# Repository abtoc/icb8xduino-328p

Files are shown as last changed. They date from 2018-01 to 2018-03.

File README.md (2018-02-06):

ICB8xduino-328p(kicadプロジェクト一式)
====

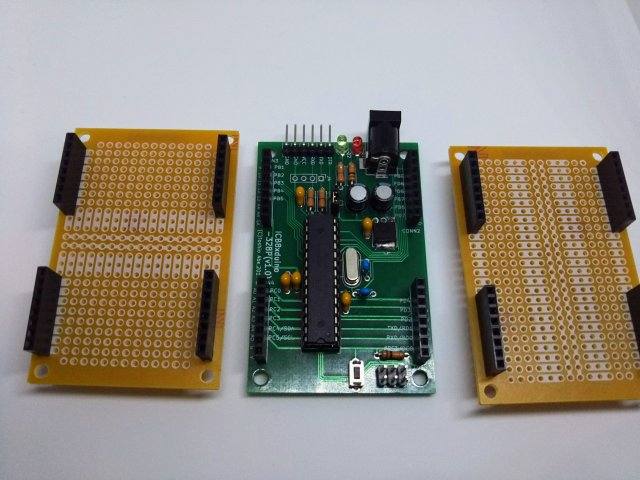
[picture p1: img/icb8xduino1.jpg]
写真1
  
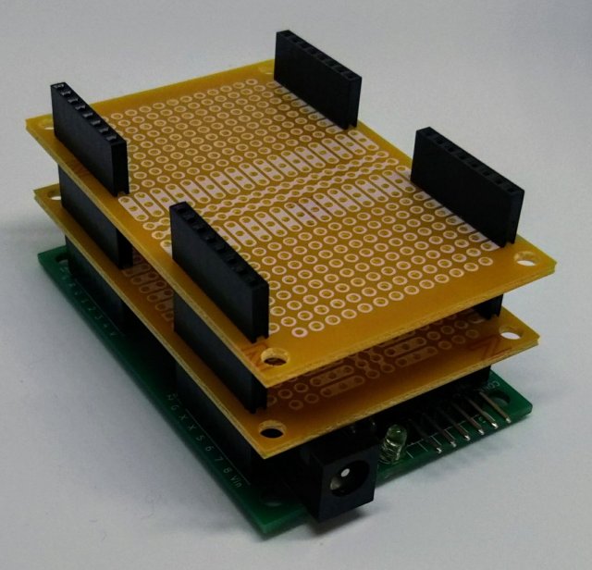
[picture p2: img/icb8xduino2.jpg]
写真2
  

ボードサイズをサンハヤト社製のICB-86,ICB-87のサイズに合わせたArduino互換基板です。
Arduino上でハードウェアのプロトタイプ作成者向けのボードになります。

目的とするシールドが無い場合は、ハードウェアの実装が必要になります。
が、下記のような問題に直面すると思います。

- 専用のユニバーサル基板を使用しなければならない
- 専用のユニバーサル基板の種類が限られる
- 100milピッチではないコネクタのため、アートワークが困難

本基板は、上記を考慮し、Arduinoプラットフォーム上で、
ハードウェア・プロトタイプ開発の手助けができれば幸いです。

## 特徴
- サイズはICB-86,ICB-87相当としています
- 基板の角のそれぞれにATmega328pのピンを全てアサインしています  
  また、ICB-86,ICB-87のコネクタパターンに合うよう配置しています

## 仕様
- ATmega328pで動作します
- クロックは16MHzクリスタル・レゾネータ及びインターナルクロック(8MHz)で動作可能です
- デジタルとアナログの電源はジャンパで分離しています
- 電源はUSBシリアル変換アダプター、ACアダプタ(コネクタ上のVINも含む)です  

## 使用方法
### 内容について
- kicadのプロジェクトファイル一式が入れられております
- ガーバーデータは garberディレクトリ に格納しております

|No. |ファイル名 |種類 |
|---:|:---|:---|
|1 |ICB8xduino-328p-F.Cu.gtl |トップレイヤ |
|2 |ICB8xduino-328p-B.Cu.gbl |ボトムレイヤ |
|3 |ICB8xduino-328p-F.Mask.gts |表面ソルダレジスト |
|4 |ICB8xduino-328p-B.Mask.gbs |裏面ソルダレジスト |
|5 |ICB8xduino-328p-F.SilkS.gto  |表面シルク |
|6 |ICB8xduino-328p-B.SilkS.gbo  |裏面シルク |
|7 |ICB8xduino-328p-Edge.Cuts.gm1|基板外形 |
|8 |ICB8xduino-328p.drl |スルーホール有ドリルデータ|
|9 |ICB8xduino-328p-NPTH.drl |スルーホール無ドリルデータ|

### [回路図](ICB8xduino-328p.pdf)

### パターン
- 前面  
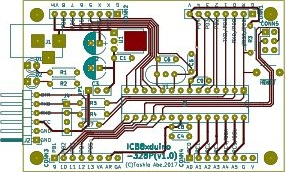
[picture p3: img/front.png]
  

- 背面  
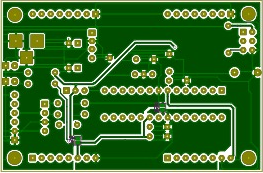
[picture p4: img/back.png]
  

### 部品表
|No. |Reference	 |部品名 |備考|
|---:|:---|:---|:---|
|1 |C1	 |積層セラミックコンデンサ 0.1μF | |
|2 |C2 	 |電解コンデンサ 47μF | |
|3 |C3 |電解コンデンサ 47μF | |
|4 |C4 |積層セラミックコンデンサ 0.1μF | |
|5 |C5  	 |積層セラミックコンデンサ 22pF |インターナルクロック、レゾネータ使用時は不要|
|6 |C6	 |積層セラミックコンデンサ 22pF |インターナルクロック、レゾネータ使用時は不要|
|7 |C7	 |積層セラミックコンデンサ 0.1μF | |
|8 |C8 |積層セラミックコンデンサ 0.1μF | |
|9 |C9 	 |積層セラミックコンデンサ 0.1μF | |
|10  |CONN1 |1x8 2.54mmピッチ ピンフレーム | |
|11  |CONN2	 |1x8 2.54mmピッチ ピンフレーム | |
|12  |CONN3	 |1x8 2.54mmピッチ ピンフレーム | |
|13  |CONN4	 |1x8 2.54mmピッチ ピンフレーム | |
|14  |CONN5	 |2x3 2.54mmピッチ ピンヘッダ | |
|15  |D1	 |3mm LED(赤) | |
|16  |D2	 |3mm LED(緑) | |
|17  |J1	 |2.1mm標準DCジャック | |
|18  |J2 	 |1x6 2.54mmピッチ ピンヘッダ(L型) | |
|19  |(J4) |秋月電子 AE-FT234X 用端子 |AT-FT234Xを使いたい場合に実装してください|
|20  |JP1	 |2x3 2.54mmピッチ ピンヘッダ | |
|21  |(JP1) |2.54ピッチ・ジャンパーピン | |
|22  |R1 	 |炭素皮膜抵抗器 10KΩ 1/4W (茶黒橙) | |
|23  |R2  	 |炭素皮膜抵抗器 330Ω 1/4W (橙橙茶) | |
|24  |R3	 |炭素皮膜抵抗器 10KΩ 1/4W (茶黒橙) | |
|25  |R4	 |炭素皮膜抵抗器 330Ω 1/4W (橙橙茶) | |
|26  |R5	 |炭素皮膜抵抗器 330Ω 1/4W (橙橙茶) | |
|27  |SW1	 |タクトスイッチ | |
|28  |U1	 |三端子レギュレータ 5V0.5A | |
|29  |U2	 |ATMEGA328P-PU | |
|30  |(U2) |ICソケット(28ピン,300mil) | |
|31  |Y1 |水晶振動子(16MHz)又はセラミック発振子(16MHz)|インターナルクロックの場合は不要|

### 実装
- GS1,GS2はハンダで接続してください。
- 内蔵クロックを使用する場合は、C5,C6及びクリスタルの実装は必要ありません。
- レゾネータを使用する場合は、C5,C6の実装は必要ありません。
- 電源をDCアダプタ(VIN端子含む)・USBシリアル変換アダプターのどちらかを、  
  ジャンパーで選択してください(回路図中JP1)
- Arduinoとして使用する場合は、AVRISP mk2でブートローダを書き込んでください  
  ブートローダ書き込み済のマイコンを使用する場合は不要です。また、
  ISCP端子も不要です
- ACアダプタの電源は三端子レギュレータの仕様に従ってください  
  本回路では12〜35Vを想定してます、

### ブートローダー書込
Arduinoとして使用する場合は、ブートローダーを書き込んでください  
※AVRISP mk2で書き込む場合

#### クリスタル、レゾネーターで使用する場合
```
avrdude \
-P usb            \
-b 19200          \
-c avrisp2        \
-p m328p          \
-v -e             \
-U efuse:w:0xFD:m \
-U hfuse:w:0xD6:m \
-U lfuse:w:0xFF:m

avrdude           \
-P usb            \
-b 19200          \
-c avrisp2        \
-p m328p          \
-v -e             \
-U lock:w:0xCF:m  \
-U flash:w:optiboot/optiboot_atmega328.hex

```

####  インターナル・クロックで使用する場合
```
avrdude \
-P usb            \
-b 19200          \
-c avrisp2        \
-p m328p          \
-v -e             \
-U efuse:w:0xFD:m \
-U hfuse:w:0xDA:m \
-U lfuse:w:0xE2:m

avrdude           \
-P usb            \
-b 19200          \
-c avrisp2        \
-p m328p          \
-v -e             \
-U lock:w:0xCF:m  \
-U flash:w:ATmegaBOOT_168_atmega328_pro_8MHz.hex
```
### スケッチ書き込み(Arduino IDE)
- スケッチの書き込みはUSBシリアル変換アダプターを使用してください  
  ピンアサインはArduino Proと同等にしてあります
- ボードの選択は下記の通りです
  - クリスタル、レゾネータの場合
    - ボード：Arduino/Genuino UNO
  - インターナルクロックの場合
    - ボード；Arduino Pro or Pro mini
    - プロセッサ：ATmega328P(3.3V, 8MHz)
- シリアルポートはUSBシリアル変換アダプターのポートを使用してください

## コネクタ
### CONN1
|No  |Aduino |ATmega328p |Pin |備考 |
|---:|---|---|---:|-----|
|1 |GNDD |GND |8 | |
|2 |RESET  |#RESET |1 | |
|3 |0 |PD0/RXD |2 | |
|4 |1 |PD1/TXD |3 | |
|5 |2 |PD2 |4 | |
|6 |3 |PD3 |5 | |
|7 |4 |PD4 |6 | |
|8 |VDD |VCC |7 | |

### CONN2
|No  |Aduino |ATmega328p |Pin |備考 |
|---:|---|---|---:|---|
|1 |GNDD |GND |8 | |
|2 |XTAL1  |PB6 |9 |内蔵クロックのみ使用可能 |
|3 |XTAL2  |PB7 |10  |内蔵クロックのみ使用可能 |
|4 |5 |PD5 |11  | |
|5 |6 |PD6 |12  | |
|6 |7 |PD7 |13  | |
|7 |8 |PB0 |14  | |
|8 |VIN |VIN |- |３端子レギュレータ入力 |

### CONN3
|No  |Aduino |ATmega328p |Pin |備考 |
|---:|---|---|---:|---|
|1 |9 |PB1 |15  | |
|2 |10 |PB2/SS |16  | |
|3 |11 |PB3/MOSI |17  | |
|4 |12 |PB4/MISO |18  | |
|5 |13 |PB5/SCK |19  | |
|6 |VCC |AVCC |20  |アナログ電源 |
|7 |AREF |AREF |21  | |
|8 |GNDA |GND |22  |アナログ電源 |

### CONN4
|No  |Aduino |ATmega328p |Pin |備考 |
|---:|---|---|---:|-----|
|1 |A0 |PC0 |23  | |
|2 |A1 |PC1 |24  | |
|3 |A2 |PC2 |25  | |
|4 |A3 |PC3 |26  | |
|5 |A4 |PC4/SDA |27  | |
|6 |A5 |PC5/SCL |28  | |
|7 |GNDD |GND |8 | |
|8 |VDD |VCC |7 | |

## ライセンス

  
基板のアートワークについては[クリエイティブ・コモンズ 表示 - 非営利 4.0 国際 ライセンス](http://creativecommons.org/licenses/by-nc/4.0/)の下に提供されています。

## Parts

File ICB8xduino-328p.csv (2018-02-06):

Reference | Value | Footprint | Datasheet | 部品名 | 備考
J1 | BARREL_JACK | Connectors:BARREL_JACK |  | 2.1mm標準DCジャック | VIN端子から電源を得る場合は不要
C1 | 0.1u | Capacitors_THT:C_Disc_D4.3mm_W1.9mm_P5.00mm |  | 積層セラミックコンデンサ 0.1μF
C2 | 47u | Capacitors_THT:CP_Radial_D6.3mm_P2.50mm |  | 電解コンデンサ 47μF
C3 | 47u | Capacitors_THT:CP_Radial_D6.3mm_P2.50mm |  | 電解コンデンサ 47μF
U1 | TA78M05F | TO_SOT_Packages_THT:SIPAK-1EP_Horizontal |  | 三端子レギュレータ 5V0.5A
JP1 | PWR | Pin_Headers:Pin_Header_Straight_1x03_Pitch2.54mm |  | 1x3 2.54mmピッチ ピンヘッダ
J2 | Serial | Pin_Headers:Pin_Header_Angled_1x06_Pitch2.54mm |  | 1x6 2.54mmピッチ ピンヘッダ(L型)
C7 | 0.1u | Capacitors_THT:C_Disc_D4.3mm_W1.9mm_P5.00mm |  | 積層セラミックコンデンサ 0.1μF
R3 | 10k | Resistors_THT:R_Axial_DIN0207_L6.3mm_D2.5mm_P7.62mm_Horizontal |  | 炭素皮膜抵抗器 10KΩ 1/4W (茶黒橙)
SW1 | RESET | ICB8xduino:SW_PUSH_Single_6mm |  | タクトスイッチ
R1 | 10k | Resistors_THT:R_Axial_DIN0207_L6.3mm_D2.5mm_P7.62mm_Horizontal |  | 炭素皮膜抵抗器 10KΩ 1/4W (茶黒橙)
D1 | RED | LEDs:LED_D3.0mm |  | 3mm LED(赤)
CONN1 | 1-7 | Pin_Headers:Pin_Header_Straight_1x08_Pitch2.54mm |  | 1x8 2.54mmピッチ ピンフレーム
CONN2 | 8-14 | Pin_Headers:Pin_Header_Straight_1x08_Pitch2.54mm |  | 1x8 2.54mmピッチ ピンフレーム
CONN3 | 15-22 | Pin_Headers:Pin_Header_Straight_1x08_Pitch2.54mm |  | 1x8 2.54mmピッチ ピンフレーム
CONN4 | 23-28 | Pin_Headers:Pin_Header_Straight_1x08_Pitch2.54mm |  | 1x8 2.54mmピッチ ピンフレーム
C5 | 22p | Capacitors_THT:C_Disc_D4.3mm_W1.9mm_P5.00mm |  | 積層セラミックコンデンサ 22pF | インターナルクロック、レゾネーター使用の場合は不要
C6 | 22p | Capacitors_THT:C_Disc_D4.3mm_W1.9mm_P5.00mm |  | 積層セラミックコンデンサ 22pF | インターナルクロック、レゾネーター使用の場合は不要
C4 | 0.1u | Capacitors_THT:C_Disc_D4.3mm_W1.9mm_P5.00mm |  | 積層セラミックコンデンサ 0.1μF
C8 | 0.1u | Capacitors_THT:C_Disc_D4.3mm_W1.9mm_P5.00mm |  | 積層セラミックコンデンサ 0.1μF
U2 | ATMEGA328-PU | Housings_DIP:DIP-28_W7.62mm_Socket |  | ATMEGA328P-PU
Y1 | 16MHz | ICB8xduino:Resonator__HC49-U_Vertical |  | 水晶振動子(16MHz)又はセラミック発振子(16MHz) | インターナルクロックの場合は不要
CONN5 | ICSP | Pin_Headers:Pin_Header_Straight_2x03_Pitch2.54mm |  | 2x3 2.54mmピッチ ピンヘッダ
C9 | 0.1u | Capacitors_THT:C_Disc_D4.3mm_W1.9mm_P5.00mm |  | 積層セラミックコンデンサ 0.1μF
R2 | 330 | Resistors_THT:R_Axial_DIN0207_L6.3mm_D2.5mm_P7.62mm_Horizontal |  | 炭素皮膜抵抗器 330Ω 1/4W (橙橙茶)
D2 | GREEN | LEDs:LED_D3.0mm |  | 3mm LED(緑)
R4 | 330 | Resistors_THT:R_Axial_DIN0207_L6.3mm_D2.5mm_P7.62mm_Horizontal |  | 炭素皮膜抵抗器 330Ω 1/4W (橙橙茶))
R5 | 330 | Resistors_THT:R_Axial_DIN0207_L6.3mm_D2.5mm_P7.62mm_Horizontal |  | 炭素皮膜抵抗器 330Ω 1/4W (橙橙茶)
J4 | AE-FT234X | Pin_Headers:Pin_Header_Straight_1x04_Pitch2.54mm
GS1 | POWER | Connectors:GS2
GS2 | GND | Connectors:GS2

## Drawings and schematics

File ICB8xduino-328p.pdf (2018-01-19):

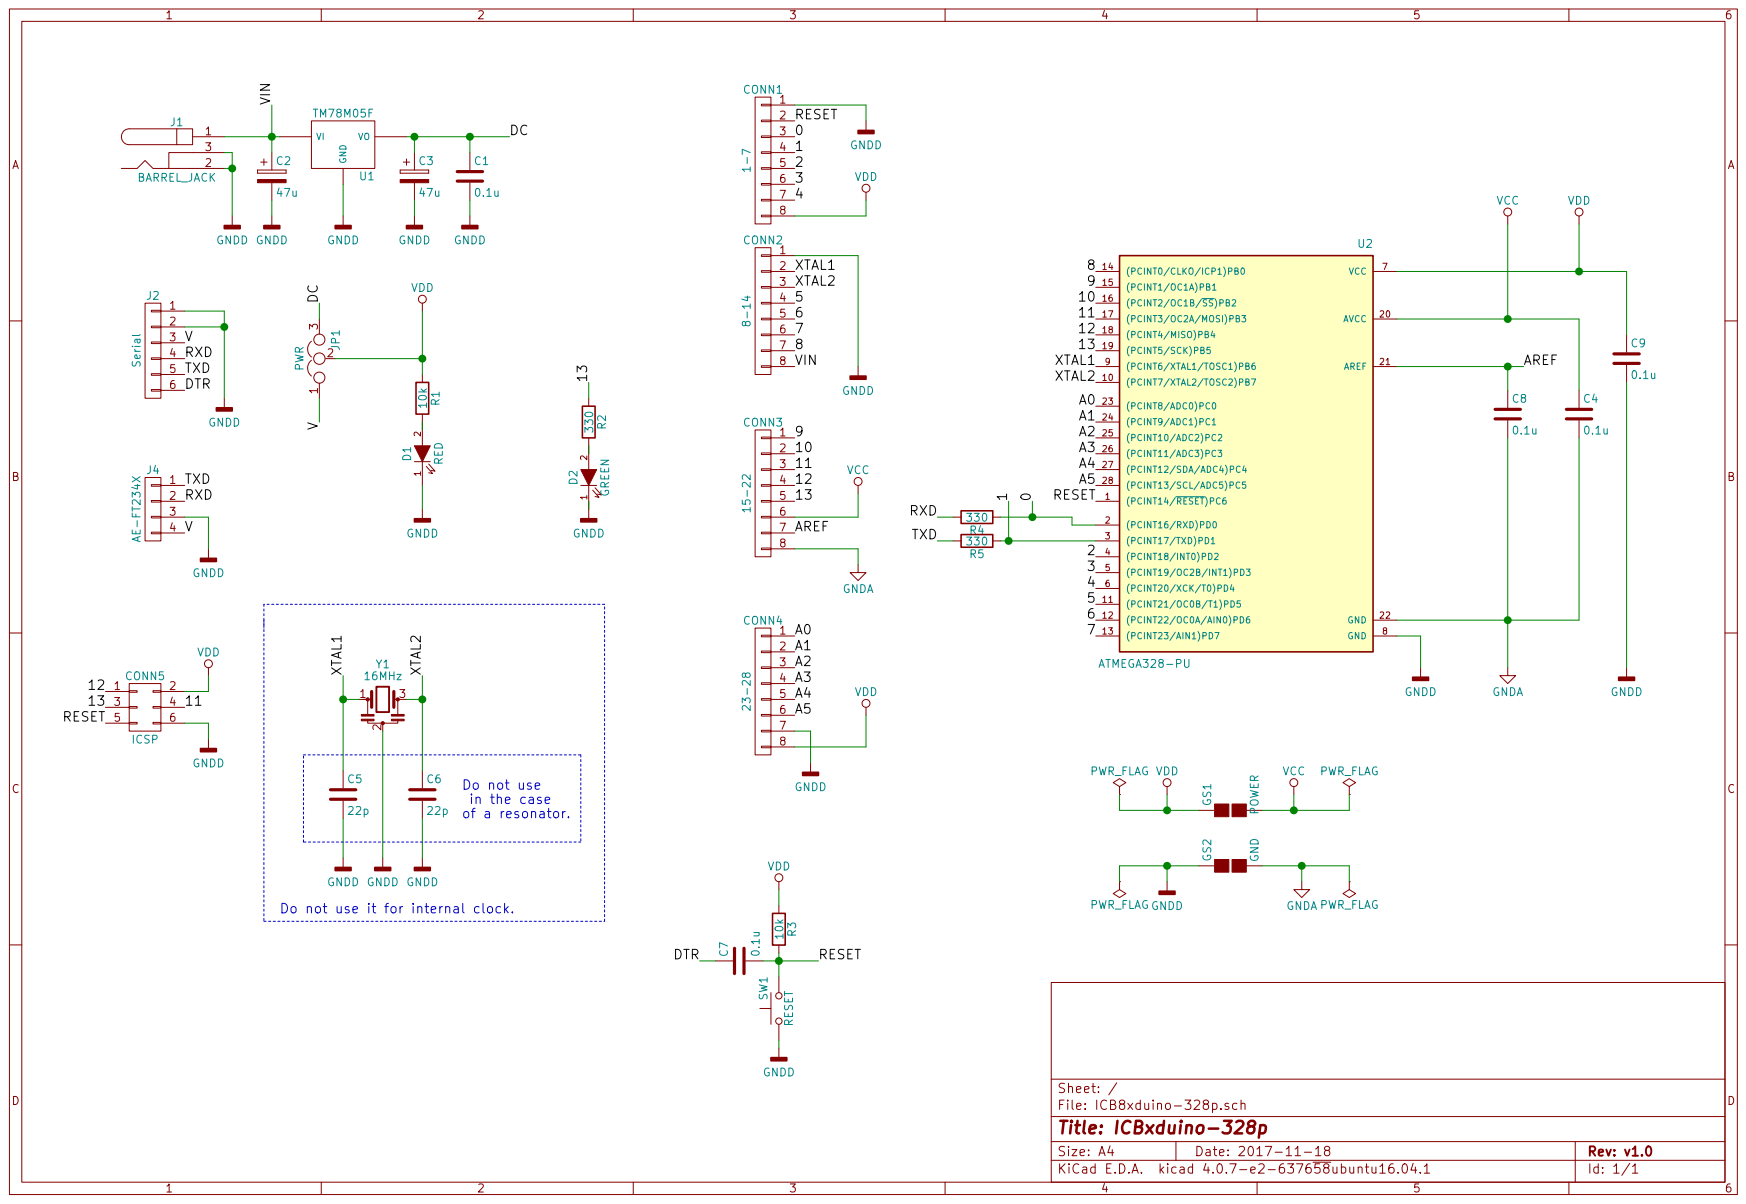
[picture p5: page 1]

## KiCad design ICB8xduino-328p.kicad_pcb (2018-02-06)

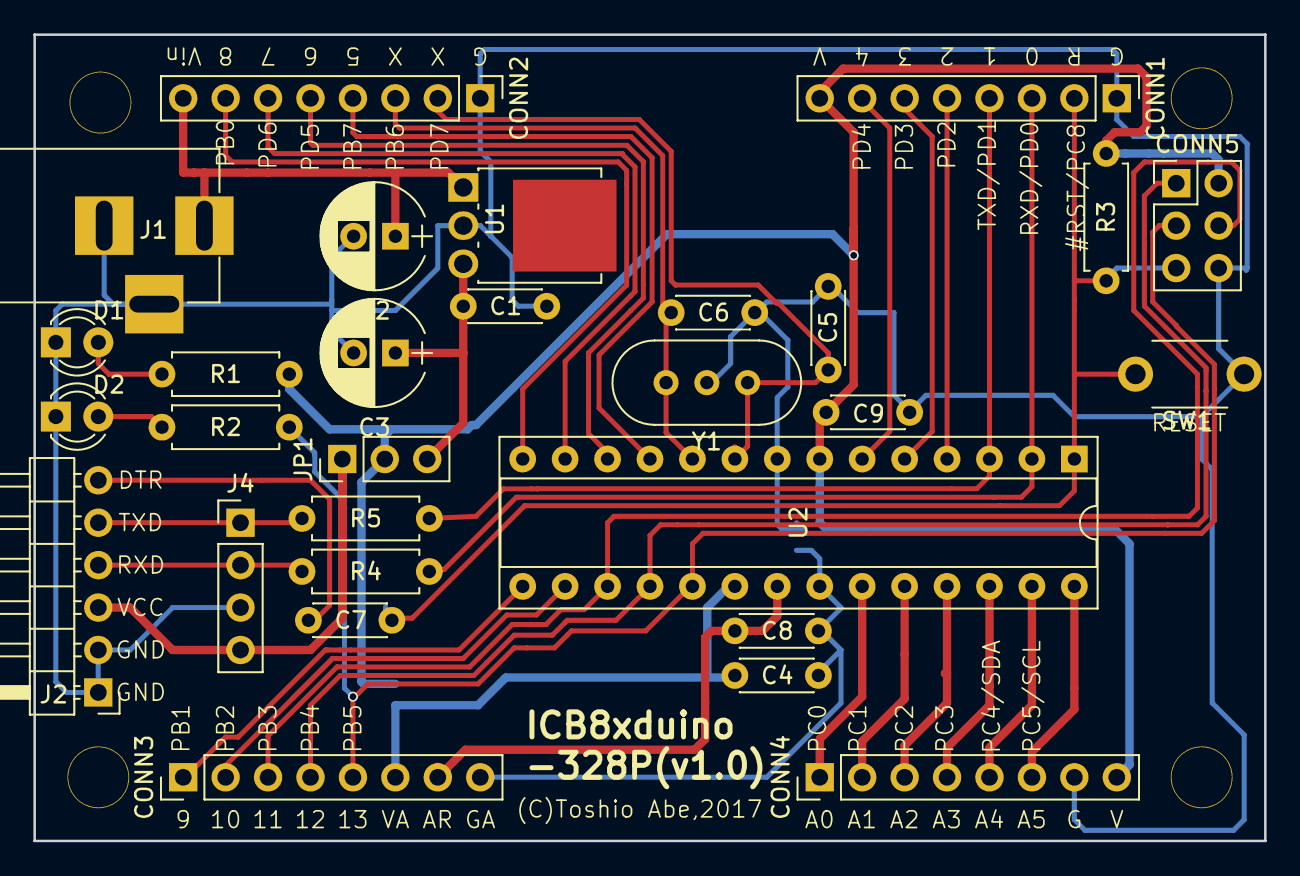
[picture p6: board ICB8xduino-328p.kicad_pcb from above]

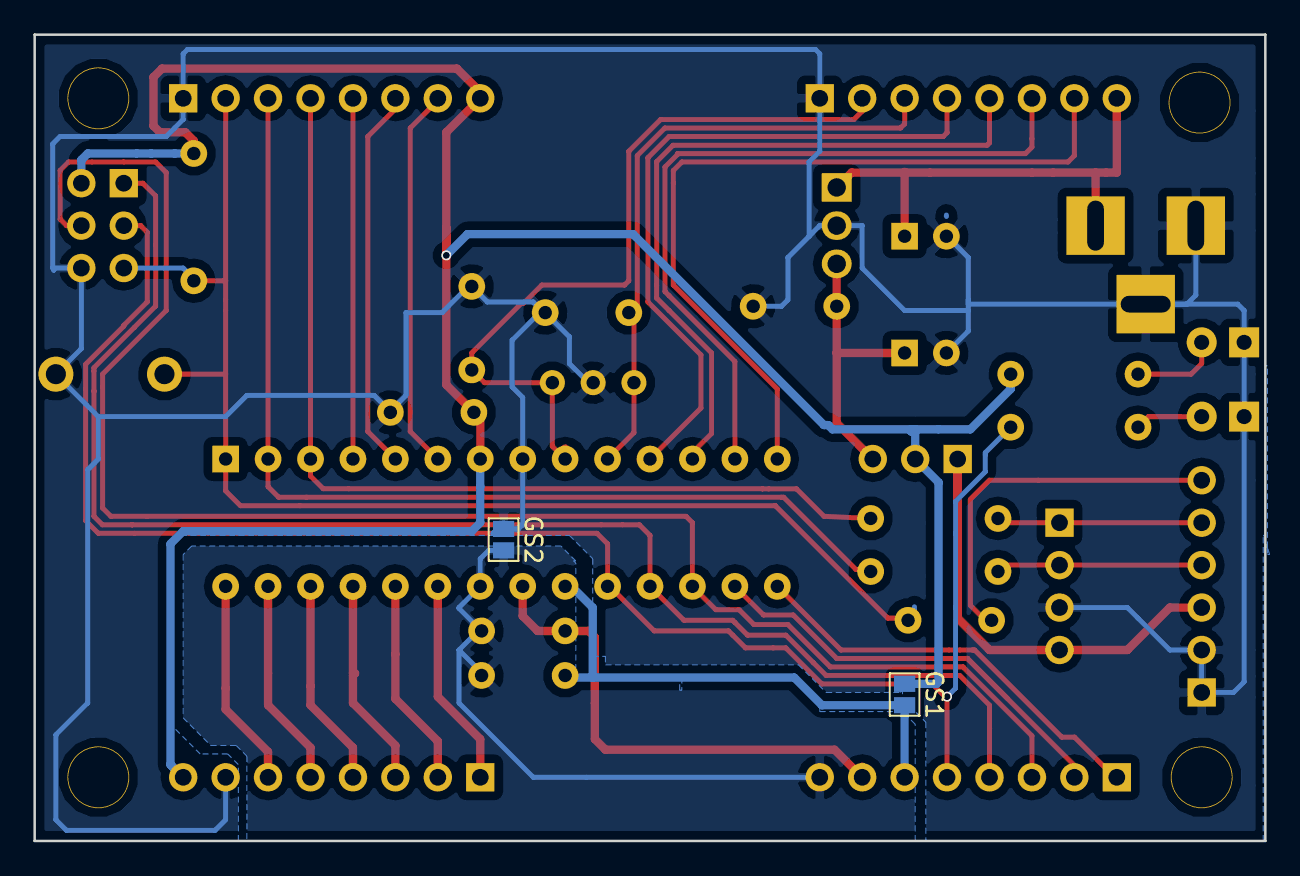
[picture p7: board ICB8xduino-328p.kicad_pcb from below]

Board: 2 copper layers, 73.7 x 48.3 mm, 31 parts (2 on the bottom side), 36 nets.

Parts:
C1, C4, C7, C8, C9: 0.1u; C_Disc_D4.3mm_W1.9mm_P5.00mm
C2, C3: 47u; CP_Radial_D6.3mm_P2.50mm
C5, C6: 22p; C_Disc_D4.3mm_W1.9mm_P5.00mm
CONN1: 1-7; Pin_Header_Straight_1x08_Pitch2.54mm
CONN2: 8-14; Pin_Header_Straight_1x08_Pitch2.54mm
CONN3: 15-22; Pin_Header_Straight_1x08_Pitch2.54mm
CONN4: 23-28; Pin_Header_Straight_1x08_Pitch2.54mm
CONN5: ICSP; Pin_Header_Straight_2x03_Pitch2.54mm
D1: RED; LED_D3.0mm
D2: GREEN; LED_D3.0mm
GS1: POWER; GS2
GS2: GND; GS2
J1: BARREL_JACK
J2: Serial; Pin_Header_Angled_1x06_Pitch2.54mm
J4: AE-FT234X; Pin_Header_Straight_1x04_Pitch2.54mm
JP1: PWR; Pin_Header_Straight_1x03_Pitch2.54mm
R1, R3: 10k; R_Axial_DIN0207_L6.3mm_D2.5mm_P7.62mm_Horizontal
R2, R4, R5: 330; R_Axial_DIN0207_L6.3mm_D2.5mm_P7.62mm_Horizontal
SW1: RESET; SW_PUSH_Single_6mm
U1: TA78M05F; SIPAK-1EP_Horizontal
U2: ATMEGA328-PU; DIP-28_W7.62mm_Socket
Y1: 16MHz; Resonator__HC49-U_Vertical

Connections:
/0: CONN1.3, R4.1, U2.2
/1: CONN1.4, R5.1, U2.3
/2: CONN1.5, U2.4
/3: CONN1.6, U2.5
/4: CONN1.7, U2.6
/5: CONN2.4, U2.11
/6: CONN2.5, U2.12
/7: CONN2.6, U2.13
/8: CONN2.7, U2.14
/9: CONN3.1, U2.15
/10: CONN3.2, U2.16
/11: CONN3.3, CONN5.4, U2.17
/12: CONN3.4, CONN5.1, U2.18
/13: CONN3.5, CONN5.3, R2.1, U2.19
/A0: CONN4.1, U2.23
/A1: CONN4.2, U2.24
/A2: CONN4.3, U2.25
/A3: CONN4.4, U2.26
/A4: CONN4.5, U2.27
/A5: CONN4.6, U2.28
/AREF: C8.1, CONN3.7, U2.21
/DC: C1.1, C3.1, JP1.3, U1.3
/DTR: C7.1, J2.6
/RESET: C7.2, CONN1.2, CONN5.5, R3.2, SW1.2, U2.1
/RXD: J2.4, J4.2, R4.2
/TXD: J2.5, J4.1, R5.2
/V: J2.3, J4.4, JP1.1
/VIN: C2.1, CONN2.8, J1.1, U1.1
/XTAL1: C5.1, CONN2.2, U2.9, Y1.1
/XTAL2: C6.1, CONN2.3, U2.10, Y1.3
GNDA: C4.2, C8.2, CONN3.8, GS2.2, U2.22
GNDD: C1.2, C2.2, C3.2, C5.2, C6.2, C9.2, CONN1.1, CONN2.1, CONN4.7, CONN5.6, D1.1, D2.1, GS2.1, J1.2, J1.3, J2.1, J2.2, J4.3, SW1.1, U1.2, U2.8, Y1.2
unnamed: D1.2, R1.2
unnamed: D2.2, R2.2
VCC: C4.1, CONN3.6, GS1.2, U2.20
VDD: C9.1, CONN1.8, CONN4.8, CONN5.2, GS1.1, JP1.2, R1.1, R3.1, U2.7

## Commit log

2018-01-19 Version 1.0版完成
    [ICB8xduino-328p.csv, ICB8xduino-328p.kicad_pcb, ICB8xduino-328p.sch]
2018-01-19 README.mdの一部を変更
2018-01-31 個別ライブラリをプロジェクトに入れた
    [ICB8xduino-328p.csv, ICB8xduino-328p.kicad_pcb, ICB8xduino-328p.sch]
2018-02-01 全体完成
    [ICB8xduino-328p.kicad_pcb]
2018-02-01 画像、ガーバーデータ追加
    [ICB8xduino-328p-B.Cu.gbl, ICB8xduino-328p-B.SilkS.gbo, ICB8xduino-328p-Edge.Cuts.gm1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]
2018-02-06 README.md見直し及びガーバーデータ作成
    [ICB8xduino-328p.csv, ICB8xduino-328p.kicad_pcb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]
2018-02-06 README.md見直し
2018-03-02 画像サイズ変更

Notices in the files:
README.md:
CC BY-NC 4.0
